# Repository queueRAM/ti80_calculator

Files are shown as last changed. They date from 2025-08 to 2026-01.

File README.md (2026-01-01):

# TI-80 Calculator Reverse Engineering

This repository contains information about the TI-80 graphing calculator hardware and firmware.
Both the main PCB from the TI-80 and the TI-80 ViewScreen capable buffer board are captured.

## Hardware
The hardware architecture contains four main devices: CPU ASIC, external ROM, external RAM,
and LCD controller. These devices are wired together on a shared 8-bit bidirectional parallel bus
and 15 bit address bus. There are separate chip select/chip enable control pins going to the
individual ROM, RAM, LCD modules.

Full schematic is included in this repository along with the notes used to markup the PCB photos.
The schematic is broken into different sections grouping related components. It does not include
all the individual test points, but includes the ones of interest. Full schematic is included in
the repository as [TI-80 schematic PDF](schematics/ti80_schematic_rev1.pdf) or KiCad.

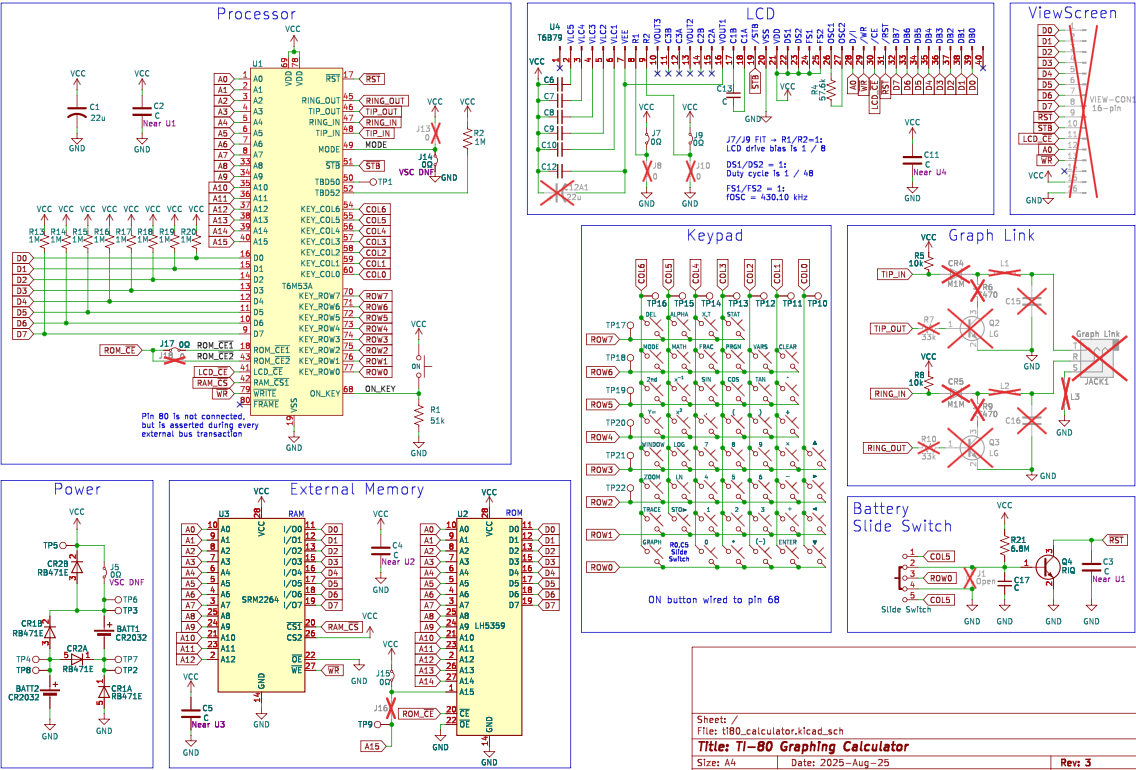
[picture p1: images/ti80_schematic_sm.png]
TI-80 Schematic


The PCB was reverse engineered using clean photos of the front and back PCB and marking up
the traces in Inkscape and probing individual pins and vias. The marked up document
can be viewed from the repository. It is stored as [TI-80 PCB layers Inkscape SVG](images/ti80_pcb_layers.svg)
with layers.

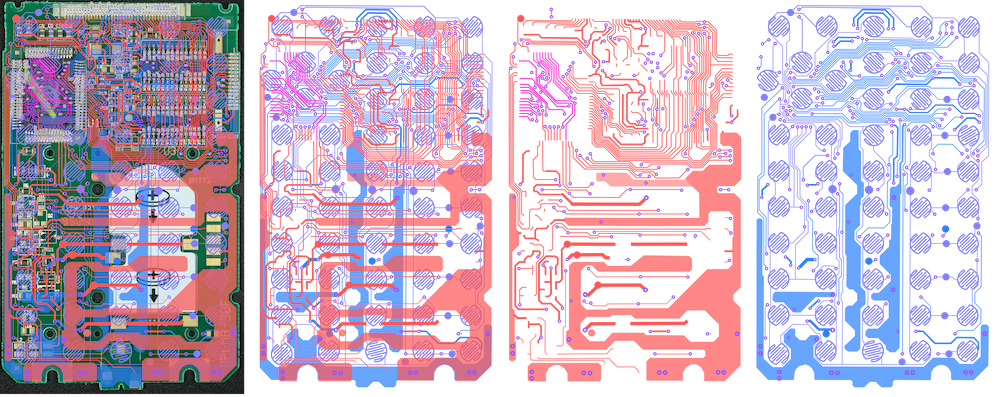
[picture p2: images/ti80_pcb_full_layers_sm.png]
Inkcape PCB Tracing


Additionally, included is the [TI-80 ViewScreen Buffer Board Schematic](ti80_viewscreen_buffer/ti80_viewscreen_buffer.pdf).
This board has two 74HC244 3-state octal buffers which pass take LCD commands sent across a ribbon cable and make
them available to the ViewScreen through the 26-pin ultra thin D-Sub cable.

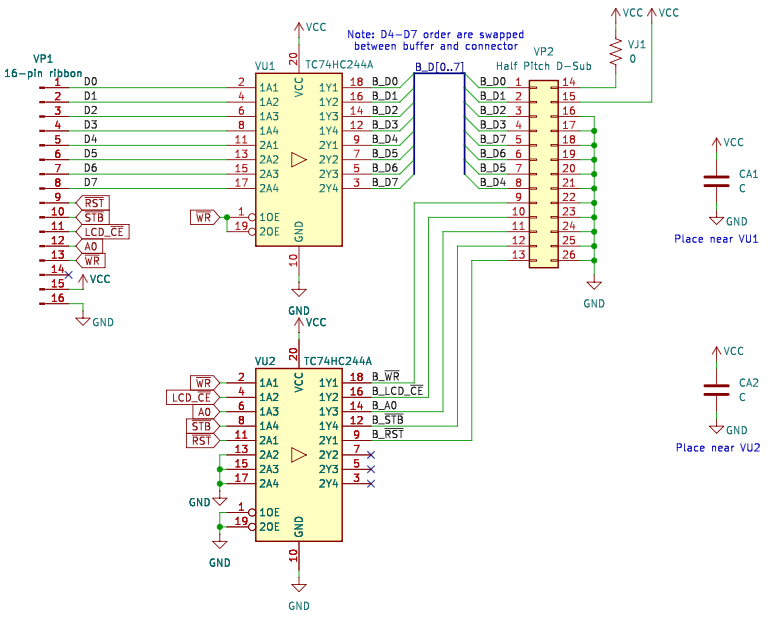
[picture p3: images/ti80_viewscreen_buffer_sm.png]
TI-80 ViewScreen Buffer Board Schematic


### Notable Parts:

REFDES | Footprint | Marking   | Manufacturer | Description       | Datasheet?
-------|-----------|-----------|--------------|-------------------|------------
 U1    | PQFP-80   | T6M53A    | Toshiba      | custom CPU ASIC   | None
 U2    | SOP-28    | LH5359    | TI           | external 32KB ROM | None, similar pinout to 23C256 or 27C256
 U3    | SOP-28    | SRM2264LM | Sharp        | external 8KB RAM  | [SRM2264LM](https://www.tautec-electronics.de/Datenblaetter/Schaltkreise/SRM2264LM.pdf)
 U4    | 40-pin    | T6B79     | Toshiba      | LCD controller    | [T6B79](https://datasheet.datasheetarchive.com/originals/distributors/Datasheets-38/DSA-757769.pdf)

### Notable findings:
1. External ROM supports up to 16 address bits, but A15 is tied high so only 32k are accessible
2. Pin 80 is unconnected, but strobes low for the duration of every external bus access (ROM, RAM, LCD)
3. Pin 52 is connected to a pull-up resistor R2 (1MΩ) so likely some sort of input. Tying this to GND doesn’t have obvious side effects
4. Pin 50 is wired out to a test pad, but not anything else. Monitoring it, seems to remain high
5. J5 shorts one of the diodes used for reverse polarity protection. This diode would like cause additional voltage drop and calculator becoming unusable due to the lower voltage powering the LCD
6. Calculator remains powered with only one battery installed, preserving the contents of SRAM. The slide switch in the battery compartment keeps /RST asserted while changing batteries. However, if manually de-asserted, the CPU, RAM, and ROM continue to run properly at 3V. The contrast of the LCD makes it unusable in this state.
7. J17/J18 control which CPU pin is connected to ROM /CE (fitted J17 = pin 18, not-fitted J18 = pin 43)

## Power
Most TI graphing calculators store programs in RAM and use a button cell battery for data retention
while swapping out the main batteries. The TI-80 also stores programs in RAM, but entirely powers
from two CR2032 batteries with no backup battery. Instead, it employs a novel physical switch in
the battery compartment that encourages the user to change one battery at a time and circuitry inside
that can keep the SRAM powered by just one button cell while the batteries are changed, and so
the data is retained. The switch also holds the CPU and LCD in reset by asserting the /RST pin
while the battery compartment slide switch is in the change battery position.

## Firmware
The TI-80 firmware is baked into the ROMs on the calculator and it is not upgradable.
The ROM is split across 16KB embedded inside the main CPU ASIC (marking T6M53A)
and 32KB in the external ROM chip (marking LH5359).

There are two known public versions of the TI-80 firmware: 3.0 and 4.0. The firmware version
can be verified by entering the self-test mode with `Mode` | `Alpha` | `S`. Zeroko's ti80doc
notes, referenced below document the differences between the two ROMs.

## Graph Link
The TI-80 does not contain a graph link port in the consumer retail versions, however, the
ViewScreen enabled version does. The only supported feature of the graph link is requesting
screen shot data. The PCB is the same between both versions, so there are unpopulated pads
in the consumer version for the graph link port and supporting circuitry.

## Notes
Special thanks to Zeroko who have contributed vast knowledge of the TI-80:
* [ti80doc](https://www.ticalc.org/archives/files/fileinfo/442/44236.html) - TI-80 calculator HW/FW documentation
* [ti80emu](https://www.ticalc.org/archives/files/fileinfo/442/44237.html) - TI-80 emulator

### Other notes on TI-80 research and ROM extraction:
* [DataMath | Texas Instruments TI-80 ViewScreen™](http://www.datamath.org/Graphing/TI-80VSC.htm)
* [MAME | TI-80 calculator CPU](https://forums.bannister.org/ubbthreads.php?ubb=showflat&Number=60414)
* [TI Planet | dumping TI-80](https://tiplanet.org/forum/viewtopic.php?f=10&t=5019)
* [Cemetech | Dumping TI-80 ROM directly](https://www.cemetech.net/forum/viewtopic.php?t=20016)
* [Cemetech | TI-80 Hardware Revisions and ViewScreenification™](https://www.cemetech.net/forum/viewtopic.php?t=15350)
* [Silicon Prawn | T6M53A die photos](https://siliconprawn.org/map/toshiba/t6m53a/marmontel_mz_ms20x/)
* [onidev | T6M53A die photos](https://ic.onidev.fr/map/T6M53A.html)

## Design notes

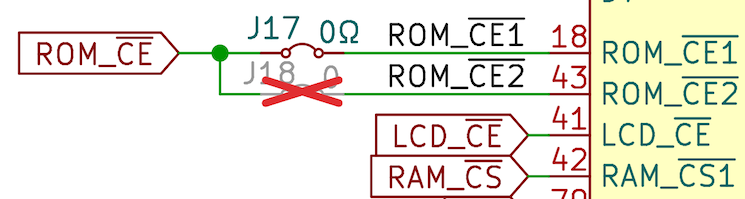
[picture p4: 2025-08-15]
images/findings/ti80_rom_ce_J17_J18.png

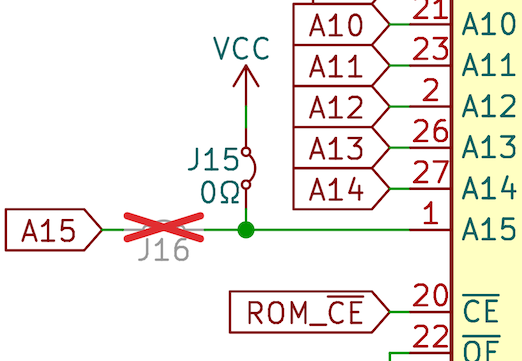
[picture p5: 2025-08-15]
images/findings/ti80_a15_pin.png

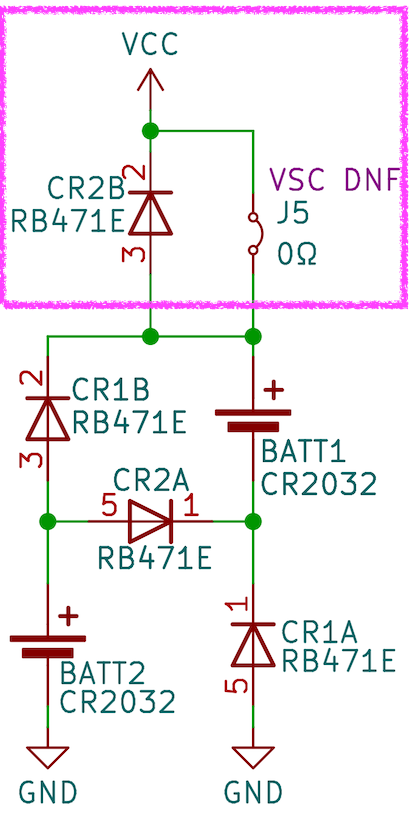
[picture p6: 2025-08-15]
images/findings/ti80_power_circuitry.png

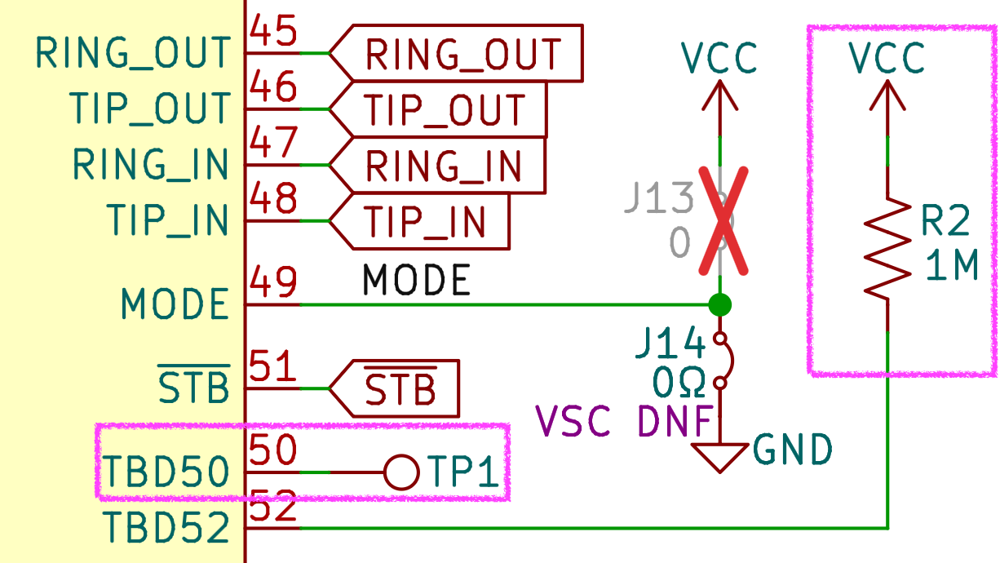
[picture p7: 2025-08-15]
images/findings/ti80_pin50_pin52.png

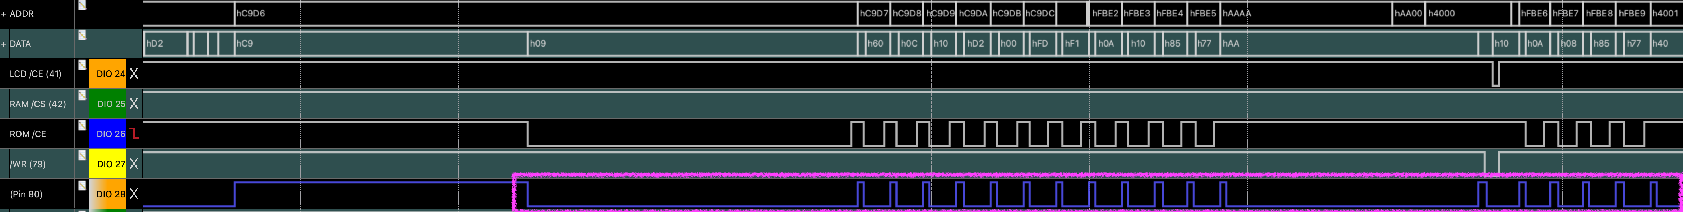
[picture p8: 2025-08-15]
images/findings/ti80_pin80_logic_trace.png

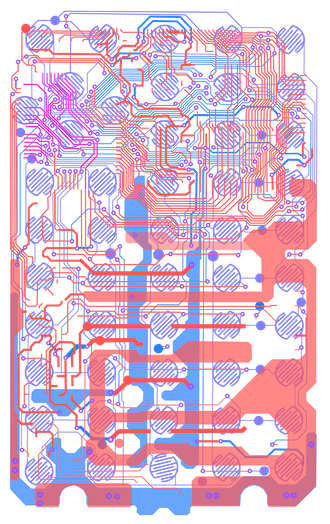
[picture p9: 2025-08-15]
images/ti80_pcb_layers_sm.png

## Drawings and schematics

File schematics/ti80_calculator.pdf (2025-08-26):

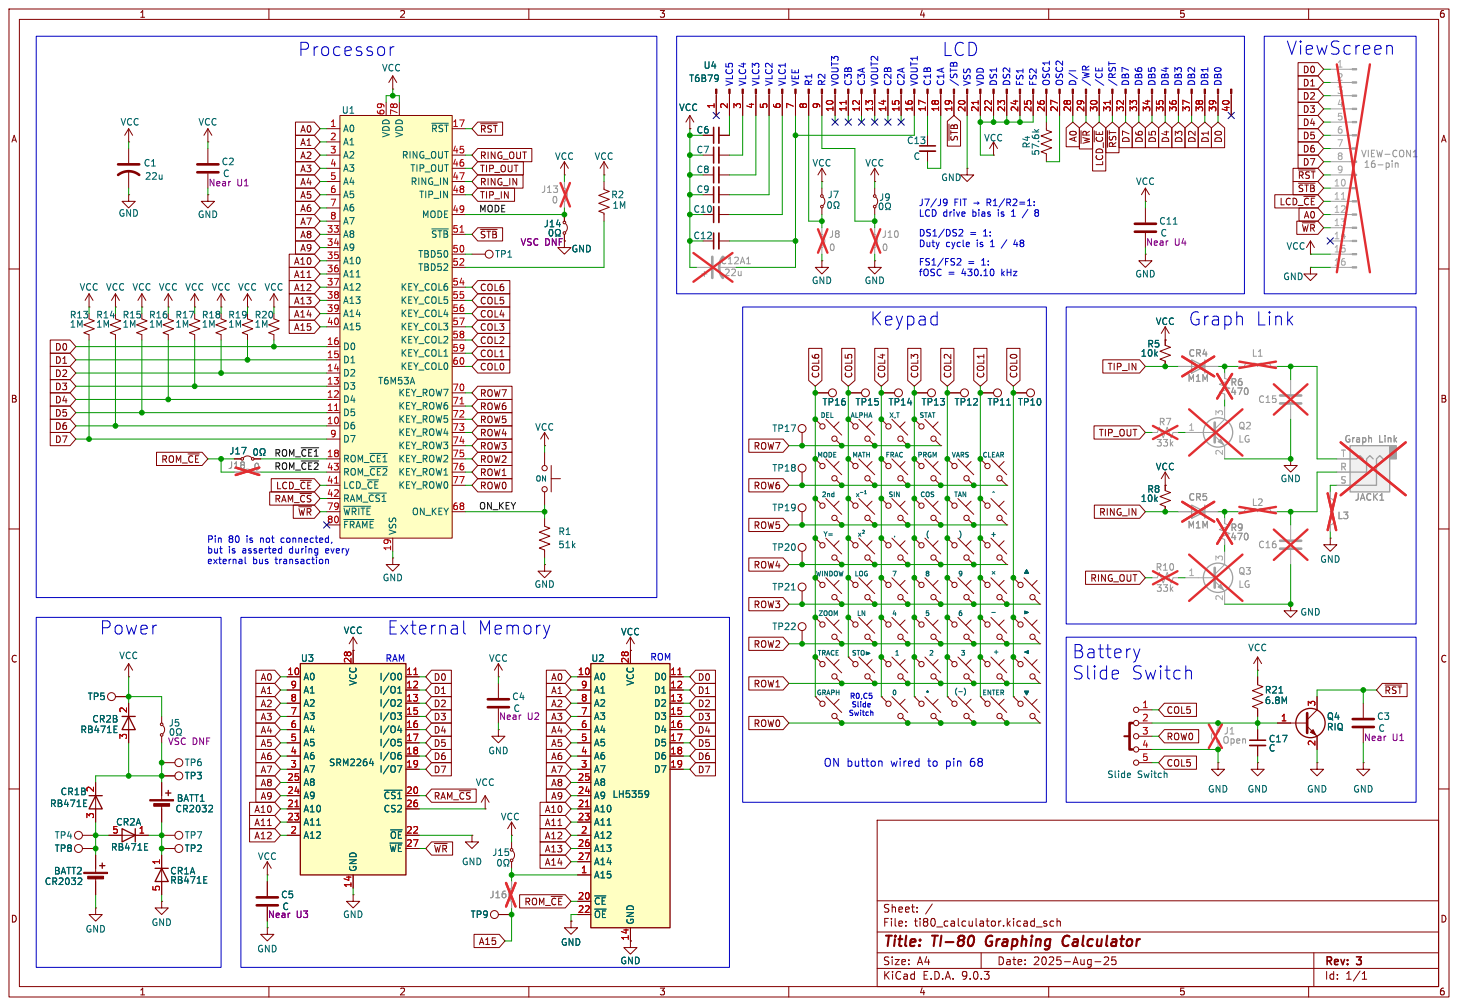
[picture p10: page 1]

- þÿ%º VCC VCC VCC VCC

JACK1 Graph Link L3 GND GND

R0,C5 Slide Switch External Memory

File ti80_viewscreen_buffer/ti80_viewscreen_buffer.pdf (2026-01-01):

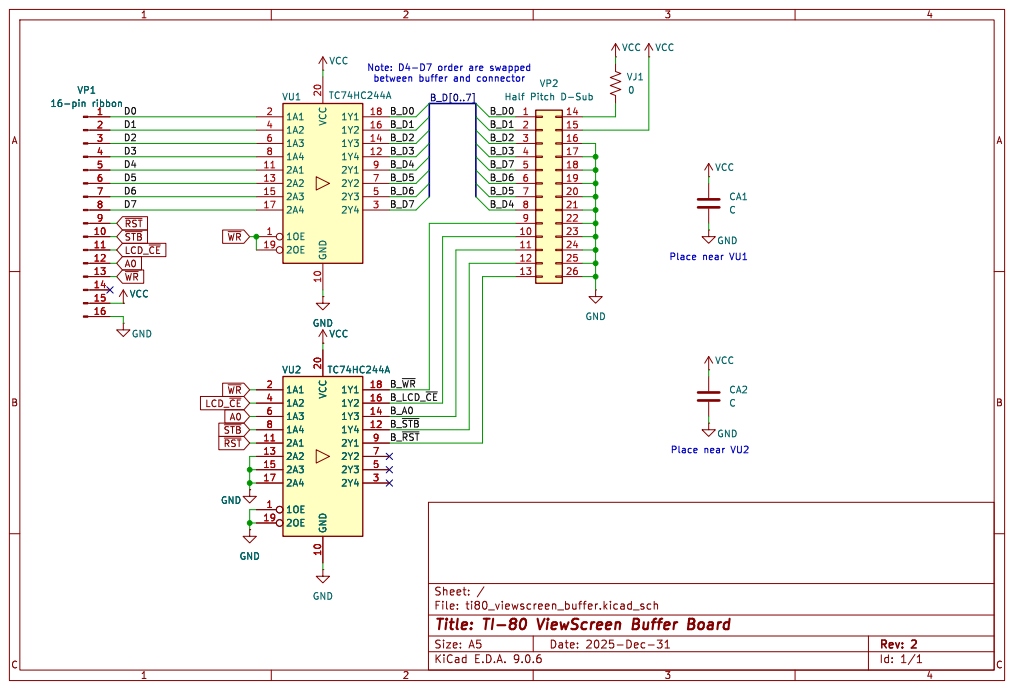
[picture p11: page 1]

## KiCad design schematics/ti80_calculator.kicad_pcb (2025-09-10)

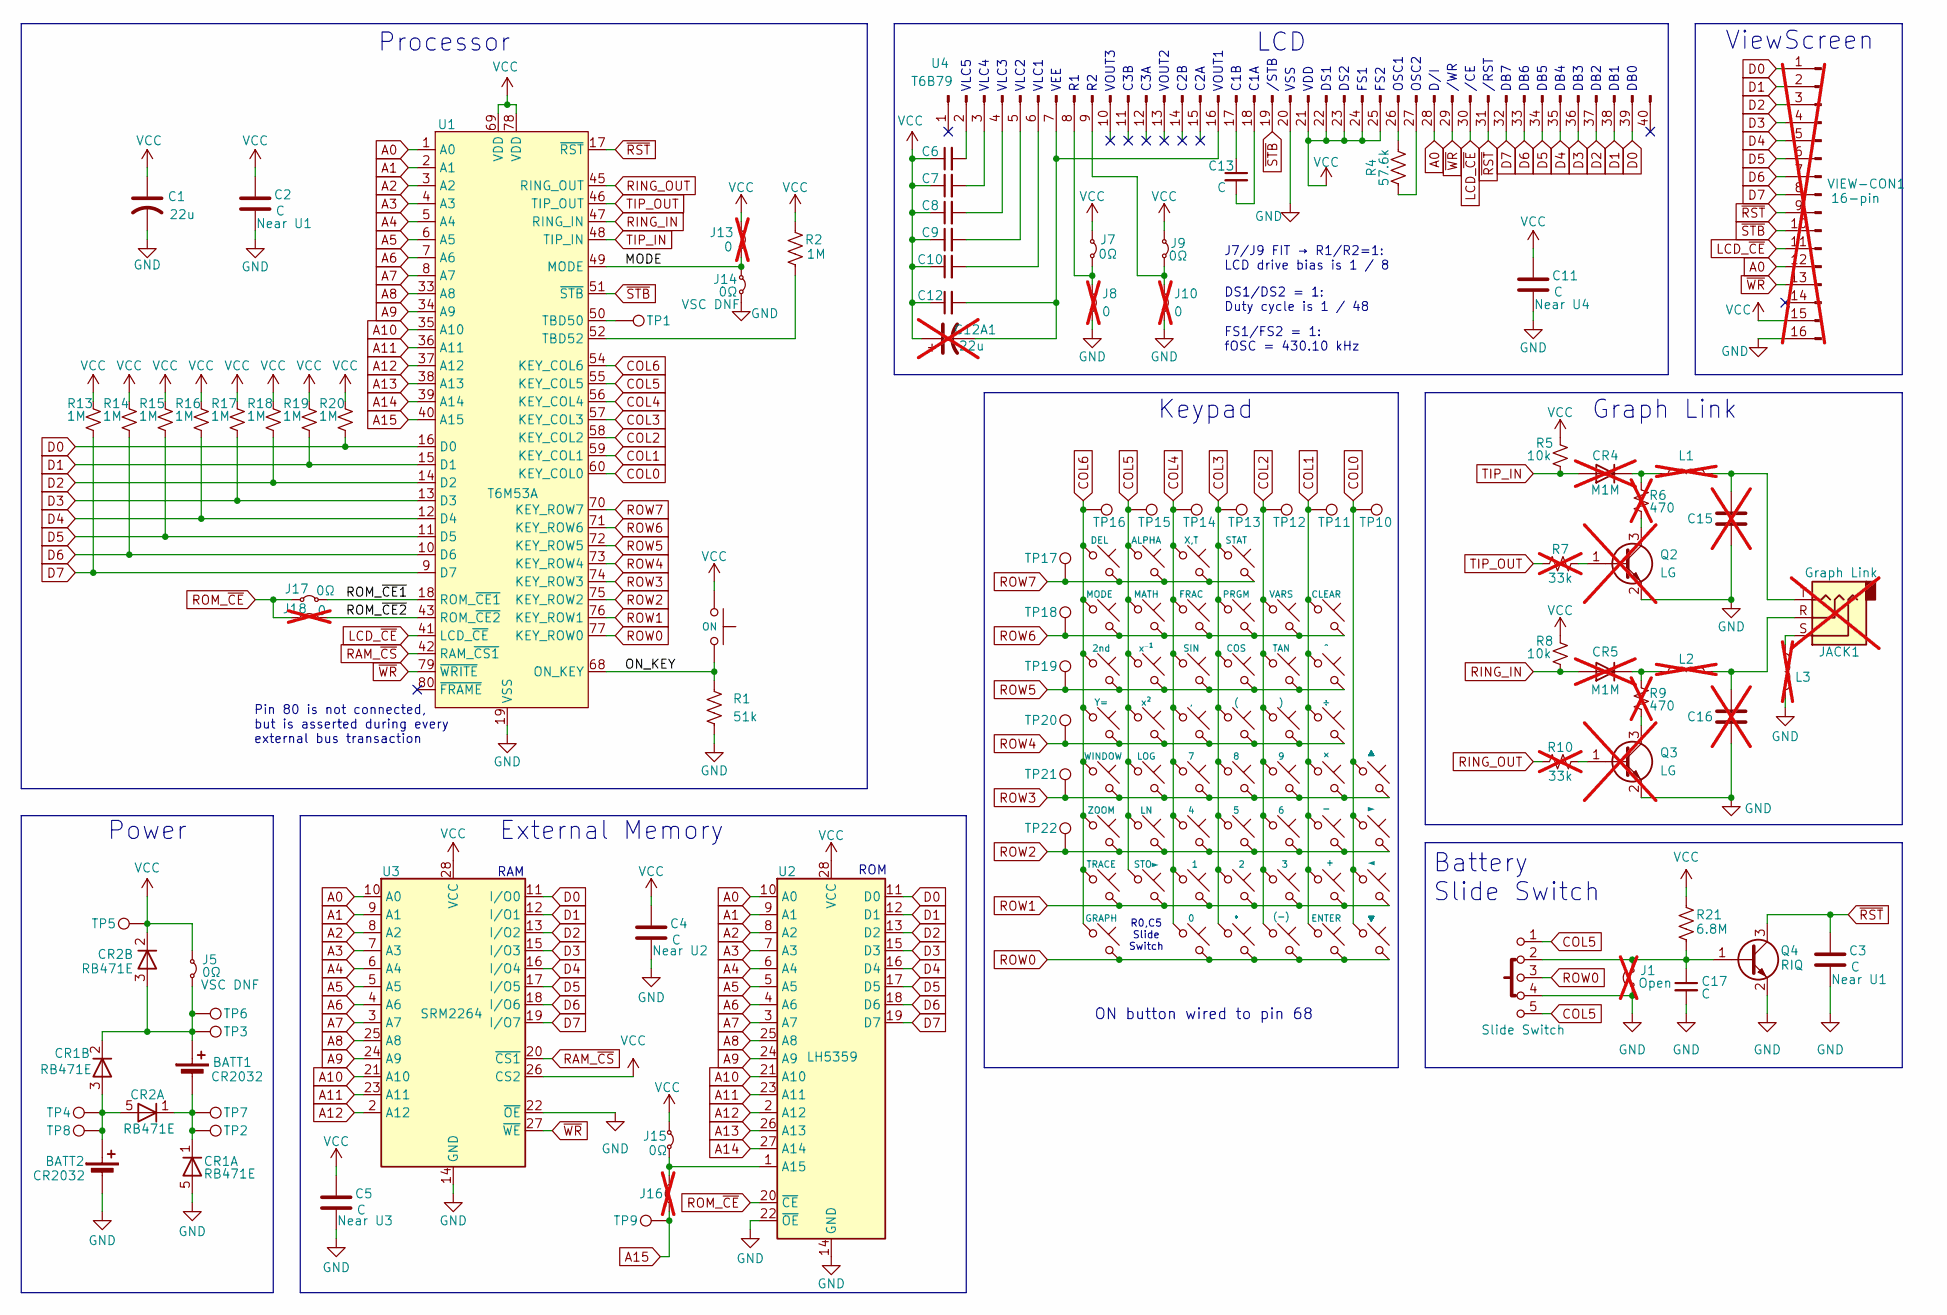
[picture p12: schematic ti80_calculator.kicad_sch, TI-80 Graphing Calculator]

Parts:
BATT1, BATT2: CR2032; Battery_Clip_CR2032
C1: 22u; CP_EIA-6032-15_Kemet-U
C2, C3, C4, C5, C6, C7, C8, C9, C10, C11, C12, C13, C17: C; C_0805_2012Metric
C12A1: 22u; CP_EIA-6032-15_Kemet-U; not fitted
C15, C16: C; C_0805_2012Metric; not fitted
CR1, CR2: RB471E; Rohm_SC-74A-5_1.55x2.9mm_P0.95mm
CR4, CR5: M1M; SOT-23; not fitted
J1: Open; R_0805_2012Metric; not fitted
J5, J7, J9, J14, J15, J17: 0Ω; R_0805_2012Metric
J8, J10, J13, J16, J18: 0; R_0805_2012Metric; not fitted
JACK1: Graph Link; Graph_Link_Jack; not fitted
L1, L2, L3: L; L_1008_2520Metric_Pad1.43x2.20mm_HandSolder; not fitted
Q2, Q3: LG; SOT-23-3; not fitted
Q4: RIQ; SOT-323_SC-70_Handsoldering
R1: 51k; R_0805_2012Metric
R2, R13, R14, R15, R16, R17, R18, R19, R20: 1M; R_0805_2012Metric
R4: 57.6k; R_1206_3216Metric
R5, R8: 10k; R_0805_2012Metric
R6, R9: 470; R_0805_2012Metric; not fitted
R7, R10: 33k; R_0805_2012Metric; not fitted
R21: 6.8M; R_0805_2012Metric
SW1: Slide Switch; Switch_Slider_5way
SW2: ON; TI80_Key
SW5: STAT; TI80_Key
SW6: X,T; TI80_Key
SW7: ALPHA; TI80_Key
SW8: DEL; TI80_Key
SW10: CLEAR; TI80_Key
SW11: VARS; TI80_Key
SW12: PRGM; TI80_Key
SW13: FRAC; TI80_Key
SW14: MATH; TI80_Key
SW15: MODE; TI80_Key
SW17: ^; TI80_Key
SW18: TAN; TI80_Key
SW19: COS; TI80_Key
SW20: SIN; TI80_Key
SW21: x⁻¹; TI80_Key
SW22: 2nd; TI80_Key
SW24: ÷; TI80_Key
SW25: ); TI80_Key
SW26: (; TI80_Key
SW27: ,; TI80_Key
SW28: x²; TI80_Key
SW29: Y=; TI80_Key
SW30: ▲; TI80_Key
SW31: ×; TI80_Key
SW32: 9; TI80_Key
SW33: 8; TI80_Key
SW34: 7; TI80_Key
SW35: LOG; TI80_Key
SW36: WINDOW; TI80_Key
SW37: ►; TI80_Key
SW38: -; TI80_Key
SW39: 6; TI80_Key
SW40: 5; TI80_Key
SW41: 4; TI80_Key
SW42: LN; TI80_Key
SW43: ZOOM; TI80_Key
SW44: ◄; TI80_Key
SW45: +; TI80_Key
SW46: 3; TI80_Key
SW47: 2; TI80_Key
SW48: 1; TI80_Key
SW49: STO►; TI80_Key
SW50: TRACE; TI80_Key
SW51: ▼; TI80_Key
SW52: ENTER; TI80_Key
SW53: (-); TI80_Key
SW54: •; TI80_Key
SW55: 0; TI80_Key
SW57: GRAPH; TI80_Key
TP1, TP2, TP3, TP4, TP5, TP6, TP7, TP8, TP9, TP10, TP11, TP12, TP13, TP14, TP15, TP16, TP17, TP18, TP19, TP20, TP21, TP22: Pin 50 Test Point; TestPoint_Pad_D2.0mm
U1: T6M53A; PQFP-80_14x20mm_P0.8mm
U2: LH5359; SOP-28_8.4x18.16mm_P1.27mm
U3: SRM2264; SOP-28_8.4x18.16mm_P1.27mm
U4: T6B79; T6B79_LCD_40pin
VIEW-CON1: 16-pin; TI80_ViewScreen; not fitted

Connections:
/MODE: J13.2 (B), J14.1 (A), U1.49 (MODE)
/ON_KEY: R1.1, SW2.1, U1.68 (ON_KEY); also elsewhere on the board
/ROM_~CE1: J17.2 (B), U1.18 (ROM_~CE1)
/ROM_~CE2: J18.2 (B), U1.43 (ROM_~CE2)
A0: U1.1 (A0), U2.10 (A0), U3.10 (A0), U4.28, VIEW-CON1.12
A1: U1.2 (A1), U2.9 (A1), U3.9 (A1)
A2: U1.3 (A2), U2.8 (A2), U3.8 (A2)
A3: U1.4 (A3), U2.7 (A3), U3.7 (A3)
A4: U1.5 (A4), U2.6 (A4), U3.6 (A4)
A5: U1.6 (A5), U2.5 (A5), U3.5 (A5)
A6: U1.7 (A6), U2.4 (A6), U3.4 (A6)
A7: U1.8 (A7), U2.3 (A7), U3.3 (A7)
A8: U1.33 (A8), U2.25 (A8), U3.25 (A8)
A9: U1.34 (A9), U2.24 (A9), U3.24 (A9)
A10: U1.35 (A10), U2.21 (A10), U3.21 (A10)
A11: U1.36 (A11), U2.23 (A11), U3.23 (A11)
A12: U1.37 (A12), U2.2 (A12), U3.2 (A12)
A13: U1.38 (A13), U2.26 (A13)
A14: U1.39 (A14), U2.27 (A14)
A15: J16.1 (A), TP9.1, U1.40 (A15)
COL0: SW30.1, SW37.1, SW44.1, SW51.1, TP10.1, U1.60 (KEY_COL0)
COL1: SW10.1, SW17.1, SW24.1, SW31.1, SW38.1, SW45.1, SW52.1, TP11.1, U1.59 (KEY_COL1)
COL2: SW11.1, SW18.1, SW25.1, SW32.1, SW39.1, SW46.1, SW53.1, TP12.1, U1.58 (KEY_COL2)
COL3: SW5.1, SW12.1, SW19.1, SW26.1, SW33.1, SW40.1, SW47.1, SW54.1, TP13.1, U1.57 (KEY_COL3)
COL4: SW6.1, SW13.1, SW20.1, SW27.1, SW34.1, SW41.1, SW48.1, SW55.1, TP14.1, U1.56 (KEY_COL4)
COL5: SW1.1, SW1.5, SW7.1, SW14.1, SW21.1, SW28.1, SW35.1, SW42.1, SW49.1, TP15.1, U1.55 (KEY_COL5)
COL6: SW8.1, SW15.1, SW22.1, SW29.1, SW36.1, SW43.1, SW50.1, SW57.1, TP16.1, U1.54 (KEY_COL6)
D0: R20.2, U1.16 (D0), U2.11 (D0), U3.11 (I/O0), U4.39, VIEW-CON1.1
D1: R19.2, U1.15 (D1), U2.12 (D1), U3.12 (I/O1), U4.38, VIEW-CON1.2
D2: R18.2, U1.14 (D2), U2.13 (D2), U3.13 (I/O2), U4.37, VIEW-CON1.3
D3: R17.2, U1.13 (D3), U2.15 (D3), U3.15 (I/O3), U4.36, VIEW-CON1.4
D4: R16.2, U1.12 (D4), U2.16 (D4), U3.16 (I/O4), U4.35, VIEW-CON1.5
D5: R15.2, U1.11 (D5), U2.17 (D5), U3.17 (I/O5), U4.34, VIEW-CON1.6
D6: R14.2, U1.10 (D6), U2.18 (D6), U3.18 (I/O6), U4.33, VIEW-CON1.7
D7: R13.2, U1.9 (D7), U2.19 (D7), U3.19 (I/O7), U4.32, VIEW-CON1.8
GND: BATT2.2 (-), C1.2, C2.2, C3.2, C4.2, C5.2, C11.2, C15.2, C16.2, C17.2, CR1.5, J1.1 (A), J8.2 (B), J10.2 (B), J14.2 (B), L3.2, Q2.2 (E), Q3.2 (E), Q4.2 (E), R1.2, SW1.4, U1.19 (VSS), U2.14 (GND), U2.22 (~OE), U3.14 (GND), U3.22 (~OE), U4.20, VIEW-CON1.16
LCD_~CE: U1.41 (LCD_~CE), U4.30, VIEW-CON1.11
unnamed: BATT1.1 (+), CR1.2, CR2.3, J5.2 (B), TP3.1, TP6.1
unnamed: BATT1.2 (-), CR1.1, CR2.1, TP2.1, TP7.1
unnamed: BATT2.1 (+), CR1.3, CR2.5, TP4.1, TP8.1
unnamed: C15.1, JACK1.T, L1.1
unnamed: C16.1, JACK1.R, L2.1
unnamed: CR4.3 (K), L1.2, R6.1
unnamed: CR5.3 (K), L2.2, R9.1
unnamed: C17.1, J1.2 (B), Q4.1 (B), R21.2, SW1.2
unnamed: J7.2 (B), J8.1 (A), U4.8
unnamed: J9.2 (B), J10.1 (A), U4.9
unnamed: J15.2 (B), J16.2 (B), U2.1 (A15)
unnamed: JACK1.S, L3.1
unnamed: Q2.1 (B), R7.2
unnamed: Q2.3 (C), R6.2
unnamed: Q3.1 (B), R10.2
unnamed: Q3.3 (C), R9.2
unnamed: TP1.1, U1.50 (TBD50)
unnamed: R2.2, U1.52 (TBD52)
unnamed: C6.2, U4.2
unnamed: C7.2, U4.3
unnamed: C8.2, U4.4
unnamed: C9.2, U4.5
unnamed: C10.2, U4.6
unnamed: C12.2, C12A1.2, U4.7, U4.16
unnamed: C13.1, U4.17
unnamed: C13.2, U4.18
unnamed: R4.2, U4.26
unnamed: R4.1, U4.27
RAM_~CS: U1.42 (RAM_~CS1), U3.20 (~CS1)
RING_IN: CR5.1 (A), R8.2, U1.47 (RING_IN)
RING_OUT: R10.1, U1.45 (RING_OUT)
ROM_~CE: J17.1 (A), J18.1 (A), U2.20 (~CE)
ROW0: SW1.3, SW51.2, SW52.2, SW53.2, SW54.2, SW55.2, SW57.2, U1.77 (KEY_ROW0); also elsewhere on the board
ROW1: SW44.2, SW45.2, SW46.2, SW47.2, SW48.2, SW49.2, SW50.2, U1.76 (KEY_ROW1); also elsewhere on the board
ROW2: SW37.2, SW38.2, SW39.2, SW40.2, SW41.2, SW42.2, SW43.2, TP22.1, U1.75 (KEY_ROW2)
ROW3: SW30.2, SW31.2, SW32.2, SW33.2, SW34.2, SW35.2, SW36.2, TP21.1, U1.74 (KEY_ROW3)
ROW4: SW24.2, SW25.2, SW26.2, SW27.2, SW28.2, SW29.2, TP20.1, U1.73 (KEY_ROW4)
ROW5: SW17.2, SW18.2, SW19.2, SW20.2, SW21.2, SW22.2, TP19.1, U1.72 (KEY_ROW5)
ROW6: SW10.2, SW11.2, SW12.2, SW13.2, SW14.2, SW15.2, TP18.1, U1.71 (KEY_ROW6)
ROW7: SW5.2, SW6.2, SW7.2, SW8.2, TP17.1, U1.70 (KEY_ROW7)
TIP_IN: CR4.1 (A), R5.2, U1.48 (TIP_IN)
TIP_OUT: R7.1, U1.46 (TIP_OUT)
VCC: C1.1, C2.1, C4.1, C5.1, C6.1, C7.1, C8.1, C9.1, C10.1, C11.1, C12.1, C12A1.1, CR2.2, J5.1 (A), J7.1 (A), J9.1 (A), J13.1 (A), J15.1 (A), R2.1, R5.1, R8.1, R13.1, R14.1, R15.1, R16.1, R17.1, R18.1, R19.1, R20.1, R21.1, SW2.2, TP5.1, U1.69 (VDD), U1.78 (VDD), U2.28 (VCC), U3.26 (CS2), U3.28 (VCC), U4.21, U4.22, U4.23, U4.24, U4.25, VIEW-CON1.15
~RST: C3.1, Q4.3 (C), U1.17 (~RST), U4.31, VIEW-CON1.9
~STB: U1.51 (~STB), U4.19, VIEW-CON1.10
~WR: U1.79 (~WRITE), U3.27 (~WE), U4.29, VIEW-CON1.13

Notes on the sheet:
VSS
C2B
FS1/FS2 = 1: fOSC = 430.10 kHz
C2A
FS1
DB2
DB3
FS2
C3A
/CE
VOUT1
VLC5
DS1/DS2 = 1: Duty cycle is 1 / 48
VEE
DB6
Keypad
Pin 80 is not connected, but is asserted during every external bus transaction
Processor
ViewScreen
ON button wired to pin 68
/RST
Power
ROM
VOUT2
DS1
RAM
Graph Link
DS2
DB5
VLC2
VOUT3
VLC1
DB7
DB1
D/I
DB0
C1B
Battery Slide Switch
C3B
OSC2

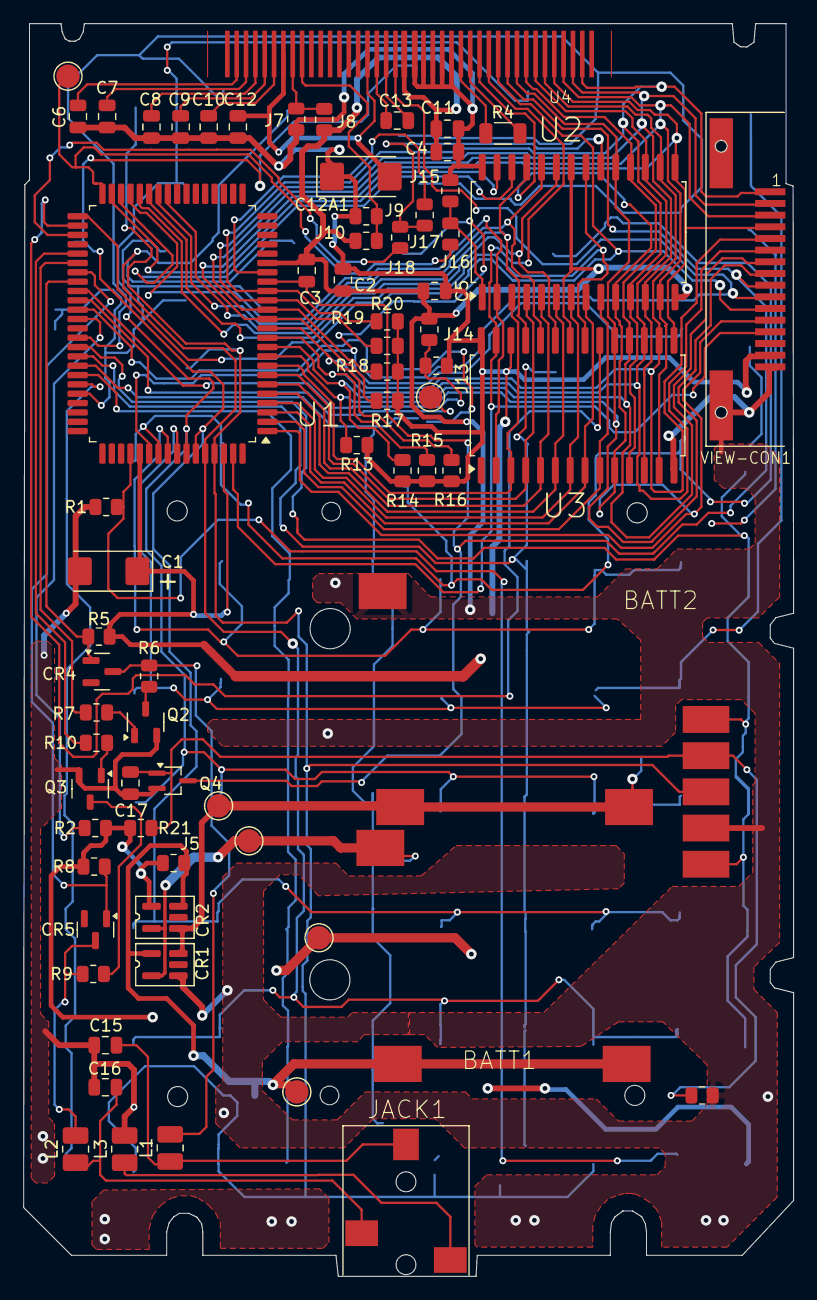
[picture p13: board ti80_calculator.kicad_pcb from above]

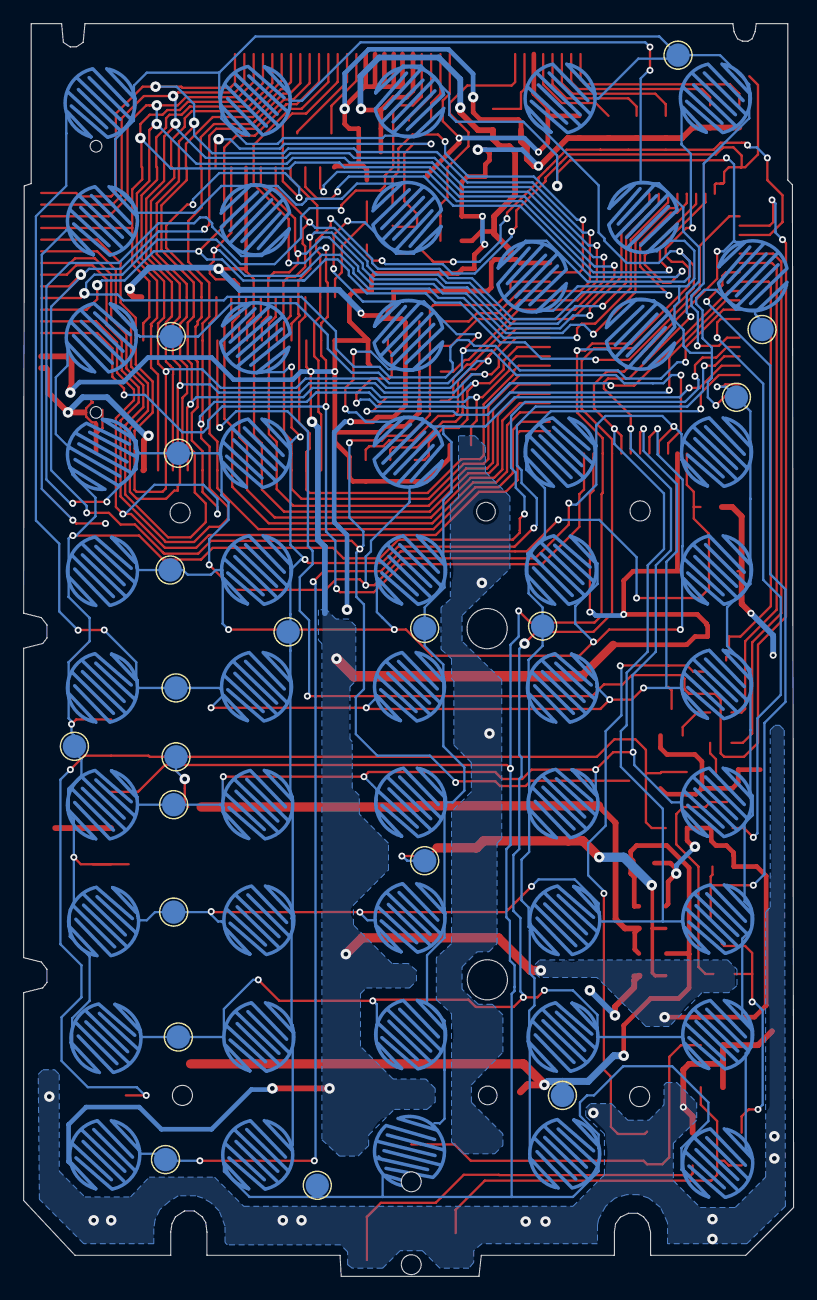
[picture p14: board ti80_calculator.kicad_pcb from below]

Board: 2 copper layers, 66.0 x 107.3 mm, 141 parts (69 on the bottom side), 83 nets.

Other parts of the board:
TP23, TP24, TP25: Pin 50 Test Point; TestPoint_Pad_D2.0mm

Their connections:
/ON_KEY: TP25.1; also elsewhere on the board
ROW0: TP24.1; also elsewhere on the board
ROW1: TP23.1; also elsewhere on the board

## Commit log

2025-08-15 Add Inkscape PCB traces and screenshots of the schematics
2025-08-15 Add TI-80 KiCad schematic, rev 1
    [ti80_calculator.kicad_sch]
2025-08-15 Add multiple layers of the PCB tracing
2025-08-15 Add ASIC Pin 80 logic trace
2025-08-15 Correct left/right arrow key rows to align with ti80doc
    [ti80_calculator.kicad_sch]
2025-08-24 Add custom TI-80 footprints and correct diode and transistor pins
    - Correct diode and transistor pinouts to reflect the packages used
    - Correct some labeling on the schematic
    - Add custom footprints for graph link jack and ViewScreen
    - Create some additional context layers in the PCB SVG
    [ti80_calculator.kicad_sch]
2025-08-24 Add PDF of rev 2 schematic
2025-08-24 Add KiCad PCB layout for TI-80
    Add two layer PCB layout for TI-80 which includes placement and routing of all symbols.
    Keypad footprints still need some work to properly finish routing.
    [ti80_calculator.kicad_pcb]
2025-08-24 Update small schematic image to reflect rev 2
2025-08-24 Add .gitignore file
    Ignores KiCad temp and local storage files and macOS .DS_Store
2025-08-24 Make PCB layout orientation portrait and add title and date
    [ti80_calculator.kicad_pcb]
2025-08-25 Update key footprint and redo keypad routing
    [ti80_calculator.kicad_pcb]
2025-08-25 Add test points for power and keypad
    - Add battery test points on front and back of PCB
    - Add test points for row and columns on keypad side of PCB
    [ti80_calculator.kicad_pcb, ti80_calculator.kicad_sch]
2025-08-26 Reorganize the bypass caps and bump rev 3
    - Clean up layout of the U2/U3 capacitors
    - Add more to title and bump revision to 3
    [ti80_calculator.kicad_sch]
2025-09-10 Change inductor package from 1210 to 1008 and hide test point silkscreens
    - 1008 is likely better package size for unpopulated graph link inductors
    - Remove the test point "TP" silkscreen labels
    [ti80_calculator.kicad_pcb, ti80_calculator.kicad_sch]
2025-12-31 Add schematic for TI-80 ViewScreen buffer board TIAPLVIS-30C
    [ti80_viewscreen_buffer.kicad_sch]
2026-01-01 Correct pinouts of TI80 viewscreen buffer board
    - 74HC244 is Toshiba which numbers 1-4 and 2nd block starts pin 11
    - 26-pin half pitch ultra thin D-Sub is top-down order
    [ti80_viewscreen_buffer.kicad_sch]
